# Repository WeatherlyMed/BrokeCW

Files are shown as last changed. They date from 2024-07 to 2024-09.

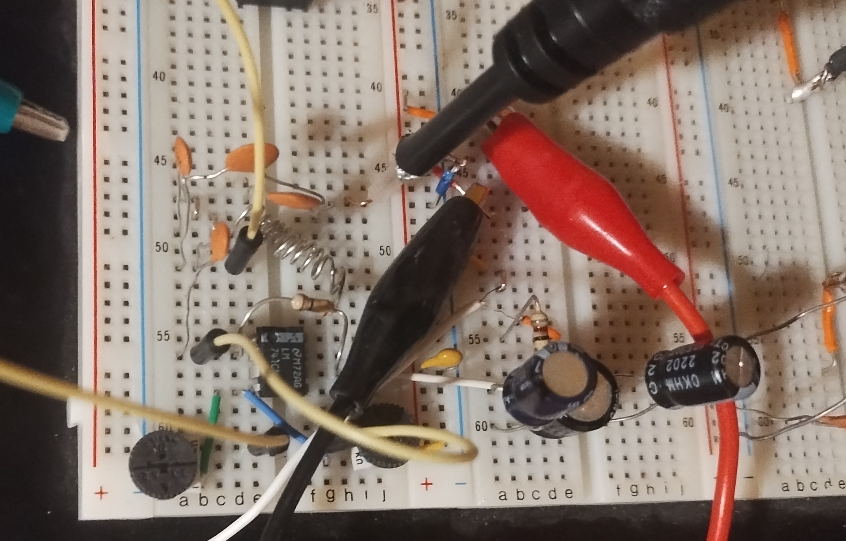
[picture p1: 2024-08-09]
receiver/testing/IMG_20240808_234810944~2.jpg

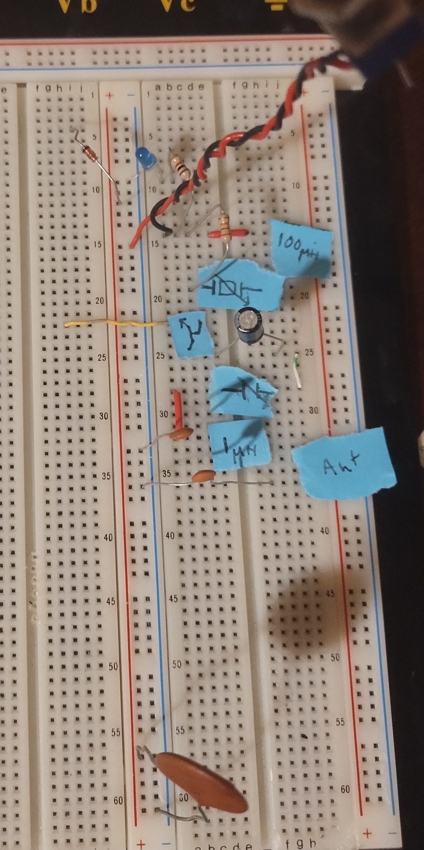
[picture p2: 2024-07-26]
artifact/withMyMaterials.jpg

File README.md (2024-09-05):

# BrokeCW
A 40m Ham Radio Transeiver build intended to be cheaper than an pixie radio while allowing for change in frequency and includes a autokey for iambic CW keyers
## Schematic for Best design with autokey: https://github.com/WeatherlyMed/BrokeCW/blob/main/artifact/ButtonSchematic.pdf


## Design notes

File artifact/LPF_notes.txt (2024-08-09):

low-pass filter (LPF) allows low-frequency signals to pass through while cuting out higher-frequency signals. 

How Low-Pass Filters Work
Basic Principle:

Pass Band: Frequencies below a certain cutoff frequency are allowed to pass through the filter.
Stop Band: Frequencies above the cutoff frequency are attenuated or blocked.
Components:

Resistor (R): Provides impedance to the circuit.
Capacitor (C): Blocks low-frequency signals but allows high-frequency signals to pass through.
Inductor (L): Blocks high-frequency signals while allowing low-frequency signals to pass.
Cutoff Frequency:

The cutoff frequency (f_c) is the point where the filter starts to attenuate the signal. It is defined by the following equations:
For RC filters: f_c = 1 / (2 * π * R * C)
For RL filters: f_c = R / (2 * π * L)
Types of Low-Pass Filters
RC Low-Pass Filter:

Components: Resistor and Capacitor.
Function: Attenuates high frequencies based on the RC time constant.
Equation: Cutoff frequency f_c = 1 / (2 * π * R * C)
Applications: Used in audio systems, signal conditioning.
RL Low-Pass Filter:

Components: Resistor and Inductor.
Function: Attenuates high frequencies based on the RL time constant.
Equation: Cutoff frequency f_c = R / (2 * π * L)
Applications: Used in power supplies and audio systems.
LC Low-Pass Filter:

Components: Inductor and Capacitor.
Function: Offers steeper attenuation than RC or RL filters due to its resonant properties.
Equation: Cutoff frequency f_c = 1 / (2 * π * sqrt(L * C))
Applications: Used in radio frequency circuits and signal processing.
Active Low-Pass Filter:

Components: Includes operational amplifiers along with resistors and capacitors.
Function: Provides gain and can be designed with various filter orders.
Applications: Used in more complex signal processing applications requiring high performance.

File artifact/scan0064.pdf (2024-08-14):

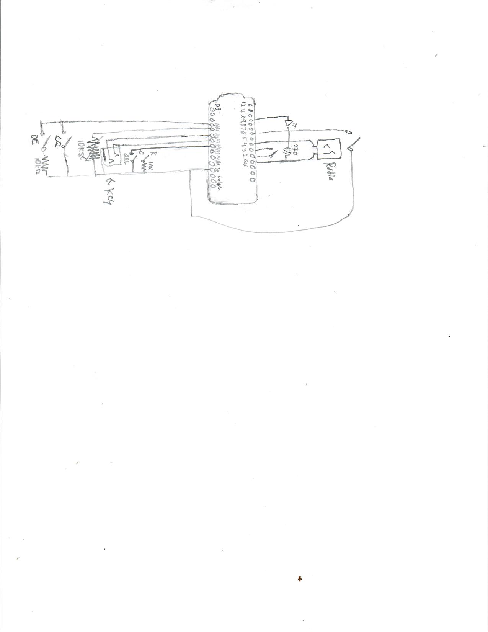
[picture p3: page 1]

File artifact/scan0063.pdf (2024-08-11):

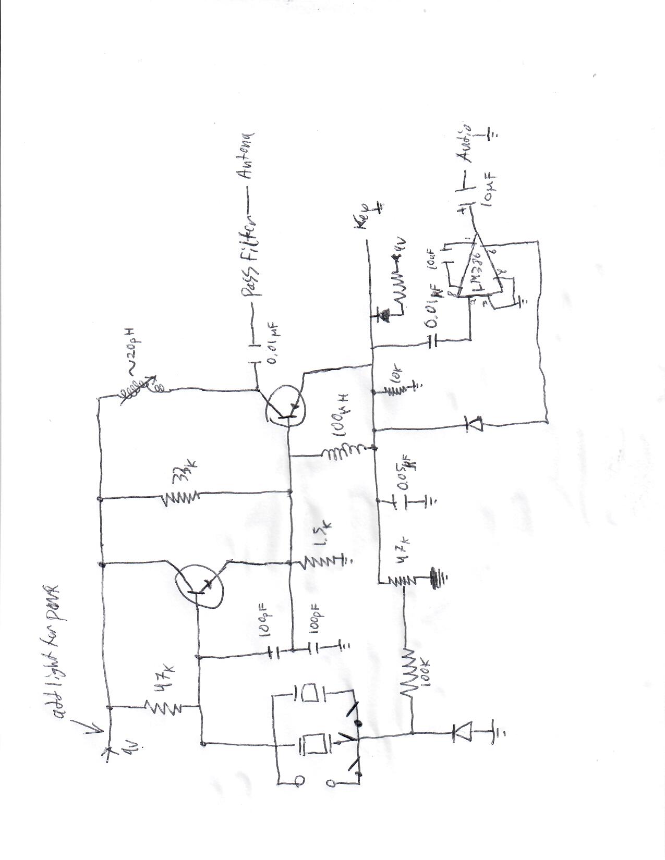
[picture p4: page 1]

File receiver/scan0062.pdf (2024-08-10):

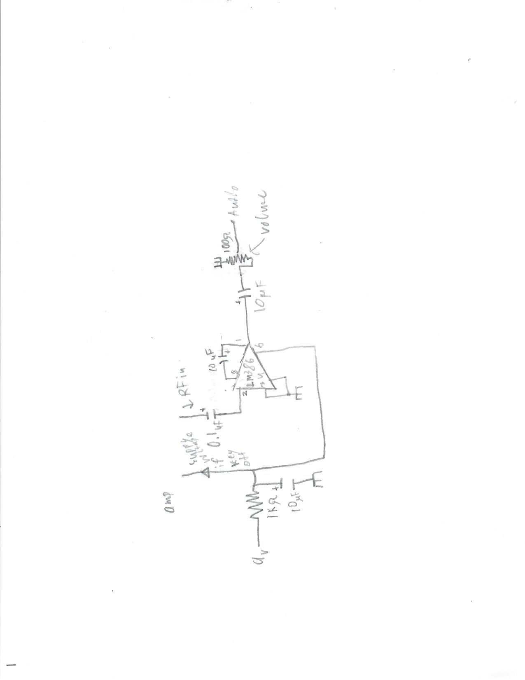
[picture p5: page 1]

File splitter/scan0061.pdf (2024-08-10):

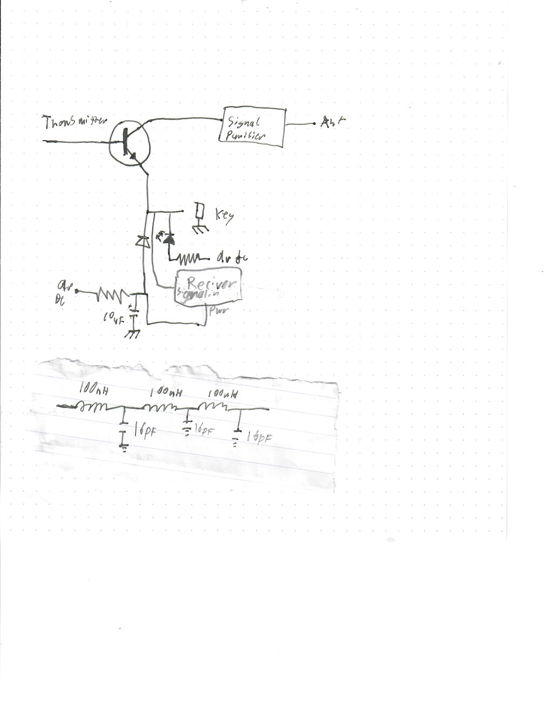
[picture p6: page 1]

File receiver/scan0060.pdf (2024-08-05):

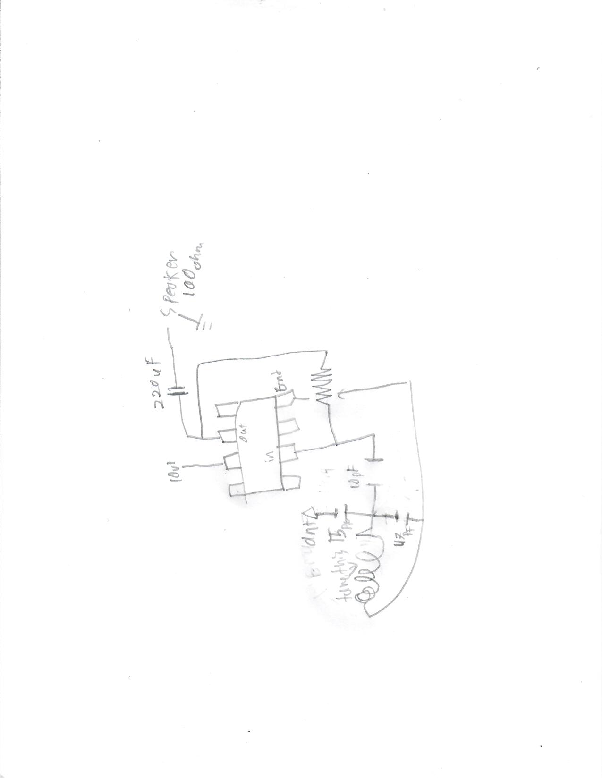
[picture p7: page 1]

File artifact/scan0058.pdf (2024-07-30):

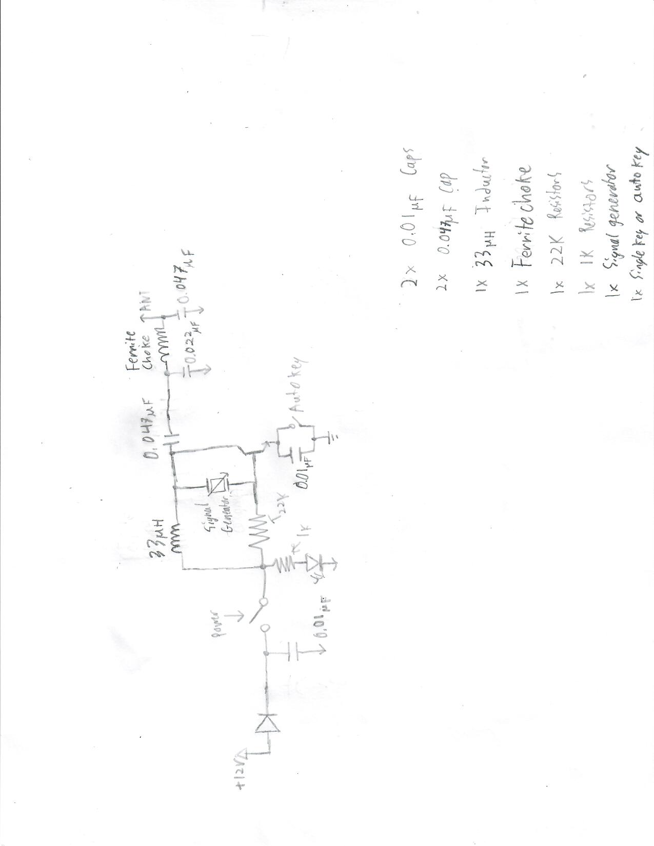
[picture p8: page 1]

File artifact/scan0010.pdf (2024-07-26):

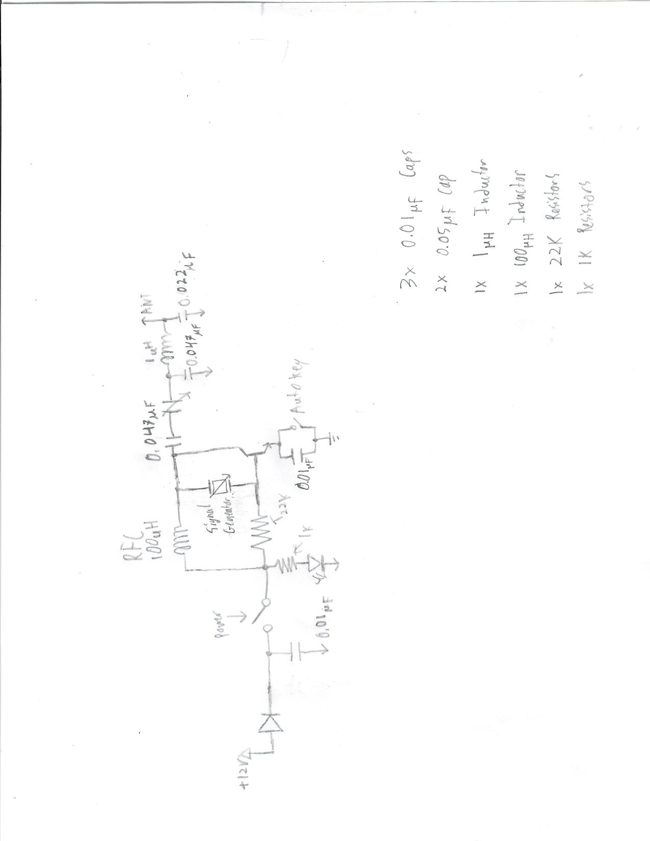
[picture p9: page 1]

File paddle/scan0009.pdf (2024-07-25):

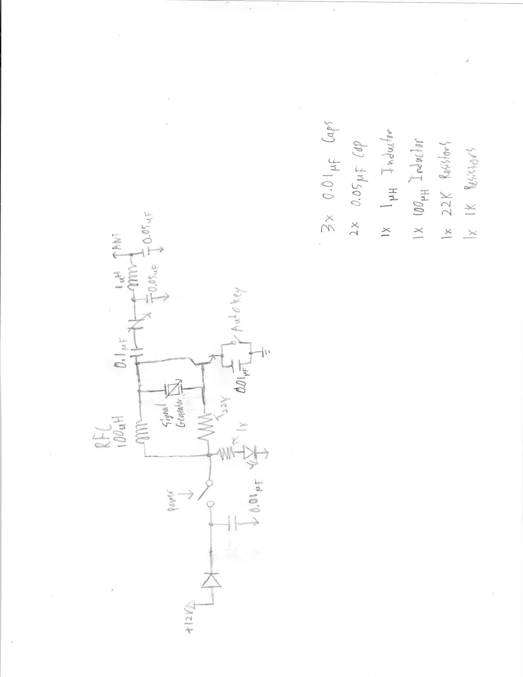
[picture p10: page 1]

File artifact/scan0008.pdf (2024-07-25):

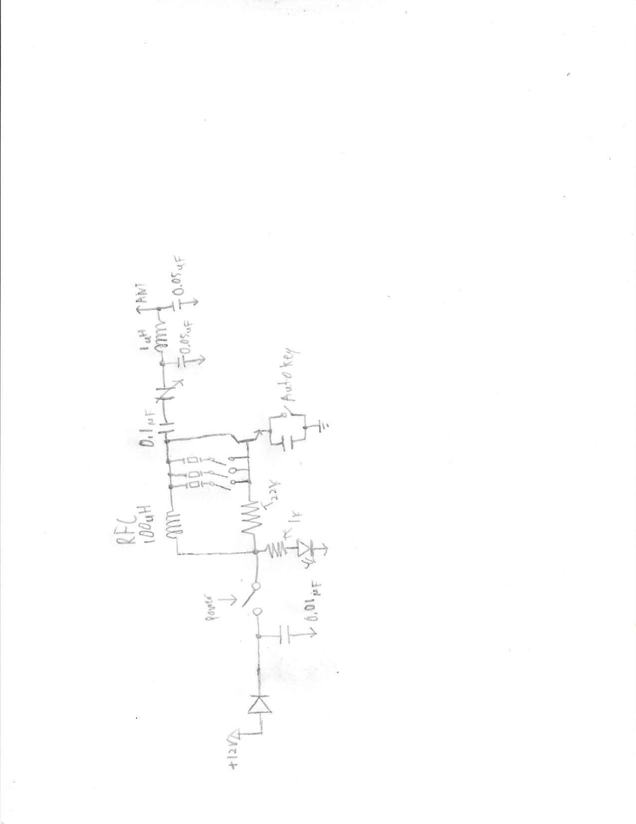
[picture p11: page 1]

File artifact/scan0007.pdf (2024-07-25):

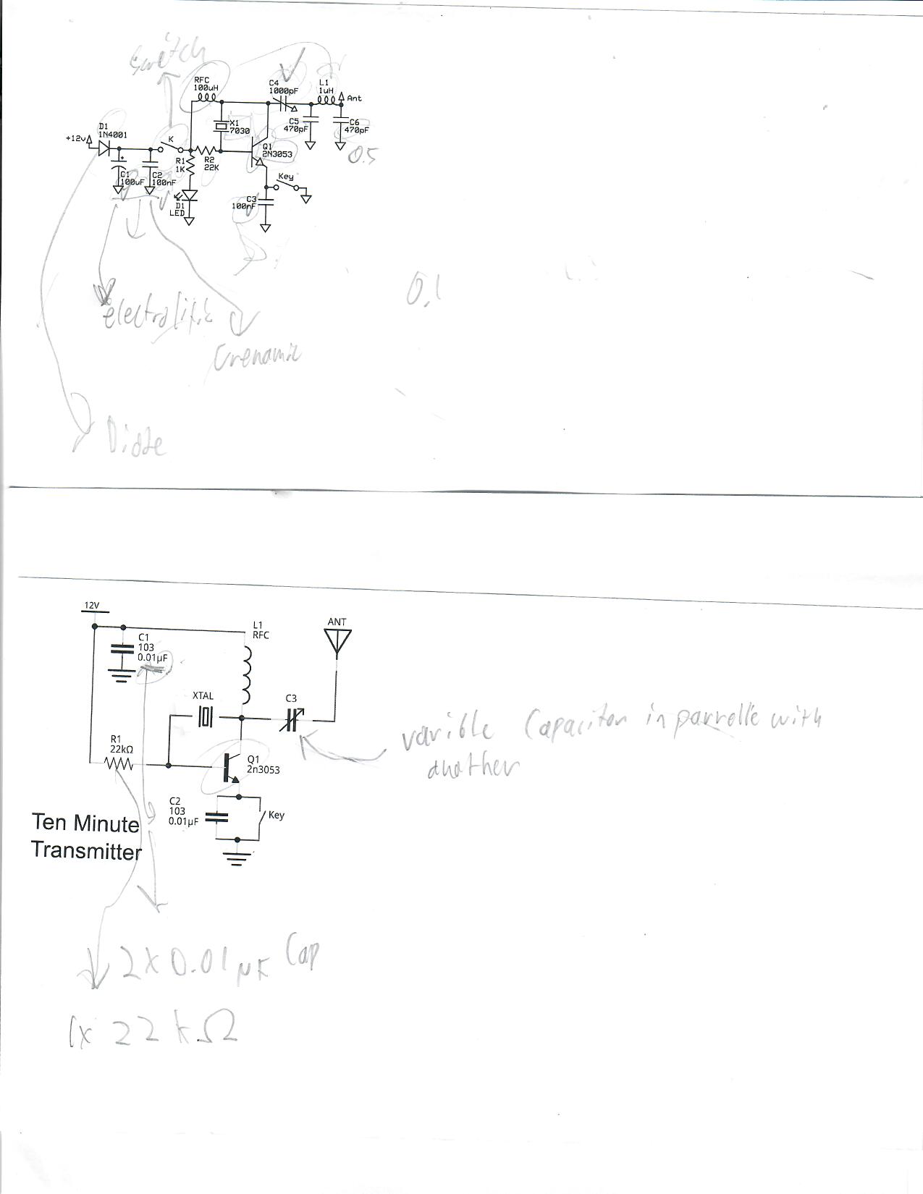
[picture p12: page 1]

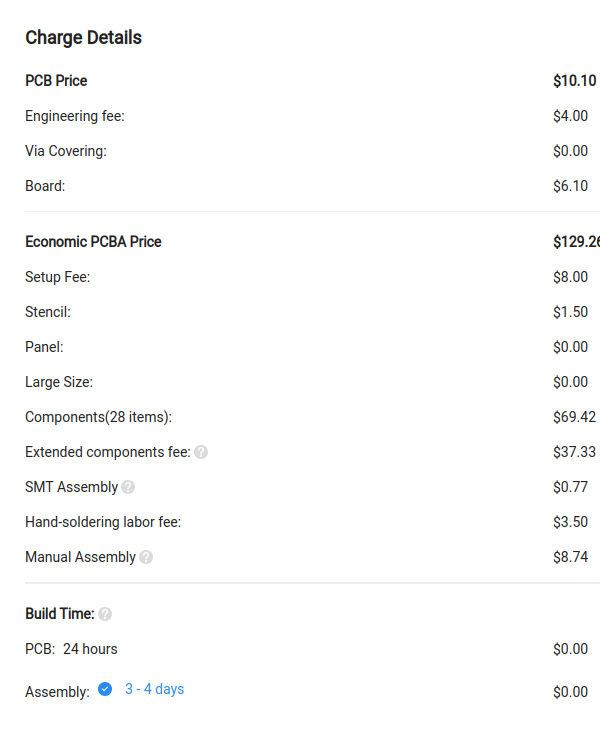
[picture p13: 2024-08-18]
artifact/Screenshot from 2024-08-17 22-34-50.png

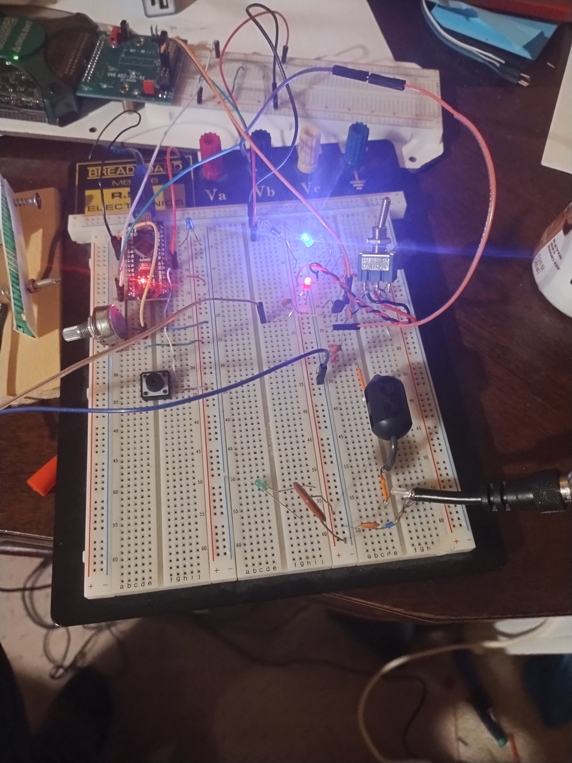
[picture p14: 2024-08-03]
artifact/IMG_20240802_214614031_HDR.jpg

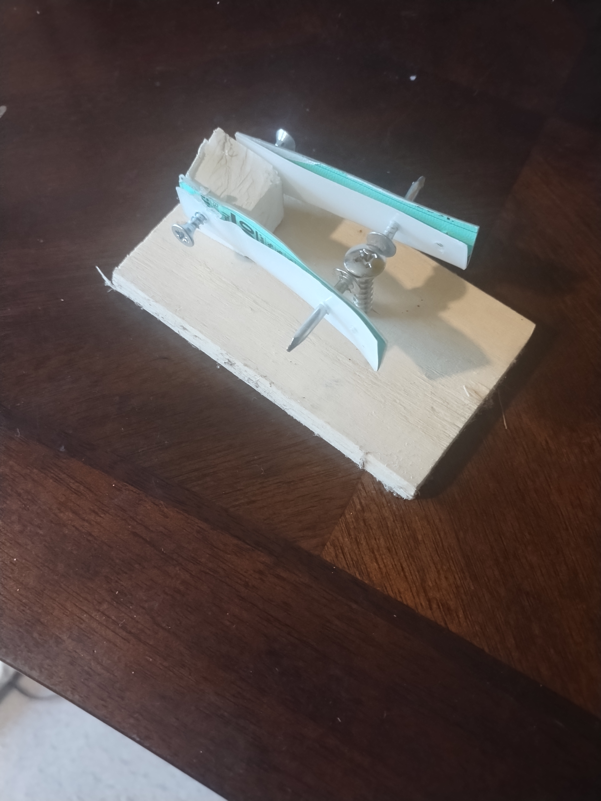
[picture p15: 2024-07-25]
paddle/Paddle.jpg

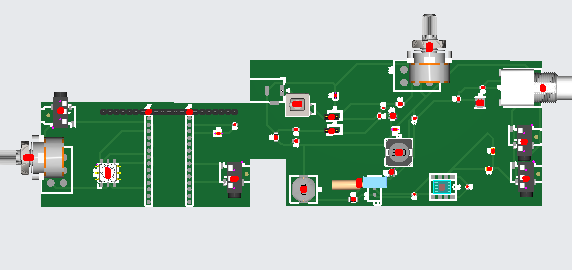
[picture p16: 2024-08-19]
artifact/Screenshot from 2024-08-18 22-14-38.png

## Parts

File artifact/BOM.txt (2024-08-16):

Resistors

2x R1: 47kΩ
CRGP2512F47K
R2: 33kΩ
AS0707J0333T5E
R3: 1kΩ
RTT121001FTP
R4: 470Ω
RTT25471JTE
R5: 10kΩ
RS-1210K1002FT
1x R6: 100kΩ 
PR02000201003JA100
R7: 10Ω
RMS10FT10R0
R8: 10kΩ
FCR1210KT10K0
R9: 220Ω
RM02FTN2200

Capacitors
C1: 0.1µF, 16V, Ceramic
CC0603KRX7R9BB104
C2: 100pF, Ceramic
CT81-6KV-07b-2b4-101K-2T3
C3: 16pF, Ceramic
C1005NP0160KGTS
C4: 10µF
CC1210ZKY5V9BB106
C3-4: 0.1uF
1H103ZC4P-3F-ZNR

Inductors
1x L1: 100µH
CY105-100uH
1x L2: 1uH
NRS4018T1R0NDGJ
1x L3: 22uH
SMDRH105R-220MT

Diodes
D2: 1N4001
C145491
D3: 1N4148
C402212

Transistors
1x Q1: 9013 (NPN Transistor) 
9013-H
Q2: 8050 (NPN Transistor)
8050-D
Crystals

Y1: 7.023MHz Crystal Oscillator(connector for it)
C22373846
Integrated Circuits

1x U1: LM386 (Low Voltage Audio Power Amplifier)

Connectors

1x J1: Power Input Connector
DC-005QB-2.0-SU-R
and
9V 100mm
1x J2: Coax Connector (for ANT)
DOSIN-801-0038
4x J3: 3.5mm Jack
C431535
3x J4: LED Indicator pink
FC-1608WPD-462M
2x J5: 15Pin Connector
B-2100S15P-A110

Miscellaneous

1x W1: 50kΩ Variable Resistor (Potentiometer)
RK16312A0BKH
1x W2 10k Variable Resistor
RK16312101A2
1x W3: 100 Varible Resistor
C330439
W4: pwr Switch
A22AB
5x W5: Option Buttons Keyer
KMS231GPLFS

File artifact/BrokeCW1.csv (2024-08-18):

Id | Designator | Footprint | Quantity | Designation | Supplier and ref
1 | J5,J6 | Hirose_DF13-03P-1.25DSA_1x03_P1.25mm_Vertical | 2 | Conn_01x03_Pin | C22373846
2 | C7 | C_Disc_D5.1mm_W3.2mm_P5.00mm | 1 | C0.01uF | C695370
3 | SW6,SW4,SW2,SW5,SW3 | SW_SPST_CK_KMS2xxGP | 5 | CK_KMS2xxGP | C318884
4 | R2 | R_1210_3225Metric | 1 | R33k | C4216
5 | C1,C2 | C_0805_2012Metric | 2 | C 10uF | C19702
6 | R4 | R_2512_6332Metric | 1 | R | C4410
7 | R1 | R_2512_6332Metric | 1 | R47k | C17713
8 | D3,D2 | LED_0402_1005Metric | 2 | LED | C2297
9 | RV2 | Potentiometer_Bourns_3296X_Horizontal | 1 | R_100ohm | C330439
10 | C4,C3 | C_Disc_D5.1mm_W3.2mm_P5.00mm | 2 | C | C1846
11 | C8,C9 | C_0402_1005Metric | 2 | C_Small | C107145
12 | RV3 | Potentiometer_Alps_RK163_Dual_Horizontal | 1 | R_Potentiometer_10k | C470593
13 | L1 | L_10.4x10.4_H4.8 | 1 | L_100uH | C5140330
14 | C6,C5 | C_Disc_D7.0mm_W2.5mm_P5.00mm | 2 | C100p | C1790
15 | R8 | Resistor_THT:R_Axial_DIN0414_L11.9mm_D4.5mm_P15.24mm_Horizontal | 1 | R_Small | 0603WAF2000T5E
16 | J4,J3 | Jack_3.5mm_KoreanHropartsElec_PJ-320D-4A_Horizontal | 2 | AudioJack3_Ground | C95562
17 | J10 | Jack_3.5mm_KoreanHropartsElec_PJ-320D-4A_Horizontal | 1 | AudioJack3_Radio | C95562
18 | L3 | L_10.4x10.4_H4.8 | 1 | L | C10165
19 | R7,R5,R3 | R_1210_3225Metric | 3 | R10K | C17902
20 | Q1 | TO-92_Inline | 1 | 9013 | C6749
21 | L2 | L_Taiyo-Yuden_MD-4040 | 1 | 1uH | C92958
22 | SW1 | SW_CK_JS202011CQN_DPDT_Straight | 1 | SW_DPDT_x2 | C712185
23 | J8 | PinHeader_1x15_P2.54mm_Vertical | 1 | Conn_01x15_PinRight | C124373
24 | J9 | Jack_3.5mm_KoreanHropartsElec_PJ-320D-4A_Horizontal | 1 | AudioJack3_Key | C95562
25 | D1 | D_DO-41_SOD81_P7.62mm_Horizontal | 1 | D_C145491 | C2128
26 | J2 | BNC_Amphenol_B6252HB-NPP3G-50_Horizontal | 1 | Conn_Coaxial | C709673
27 | J7 | PinHeader_1x15_P2.54mm_Vertical | 1 | Conn_01x15_PinLeft | C124373
28 | R6 | R_Axial_DIN0414_L11.9mm_D4.5mm_P15.24mm_Horizontal | 1 | R100k | C17900
29 | J1 | BarrelJack_Wuerth_6941xx301002 | 1 | Barrel_Jack_MountingPin | C7428648
30 | U1 | DIP-8_W7.62mm_SMDSocket_SmallPads | 1 | LM386 | C5157706
31 | RV1 | Potentiometer_Alps_RK163_Dual_Horizontal | 1 | R_Pot50k | C470593
32 | Q2 | TO-92_Inline | 1 | 8050 | C2150

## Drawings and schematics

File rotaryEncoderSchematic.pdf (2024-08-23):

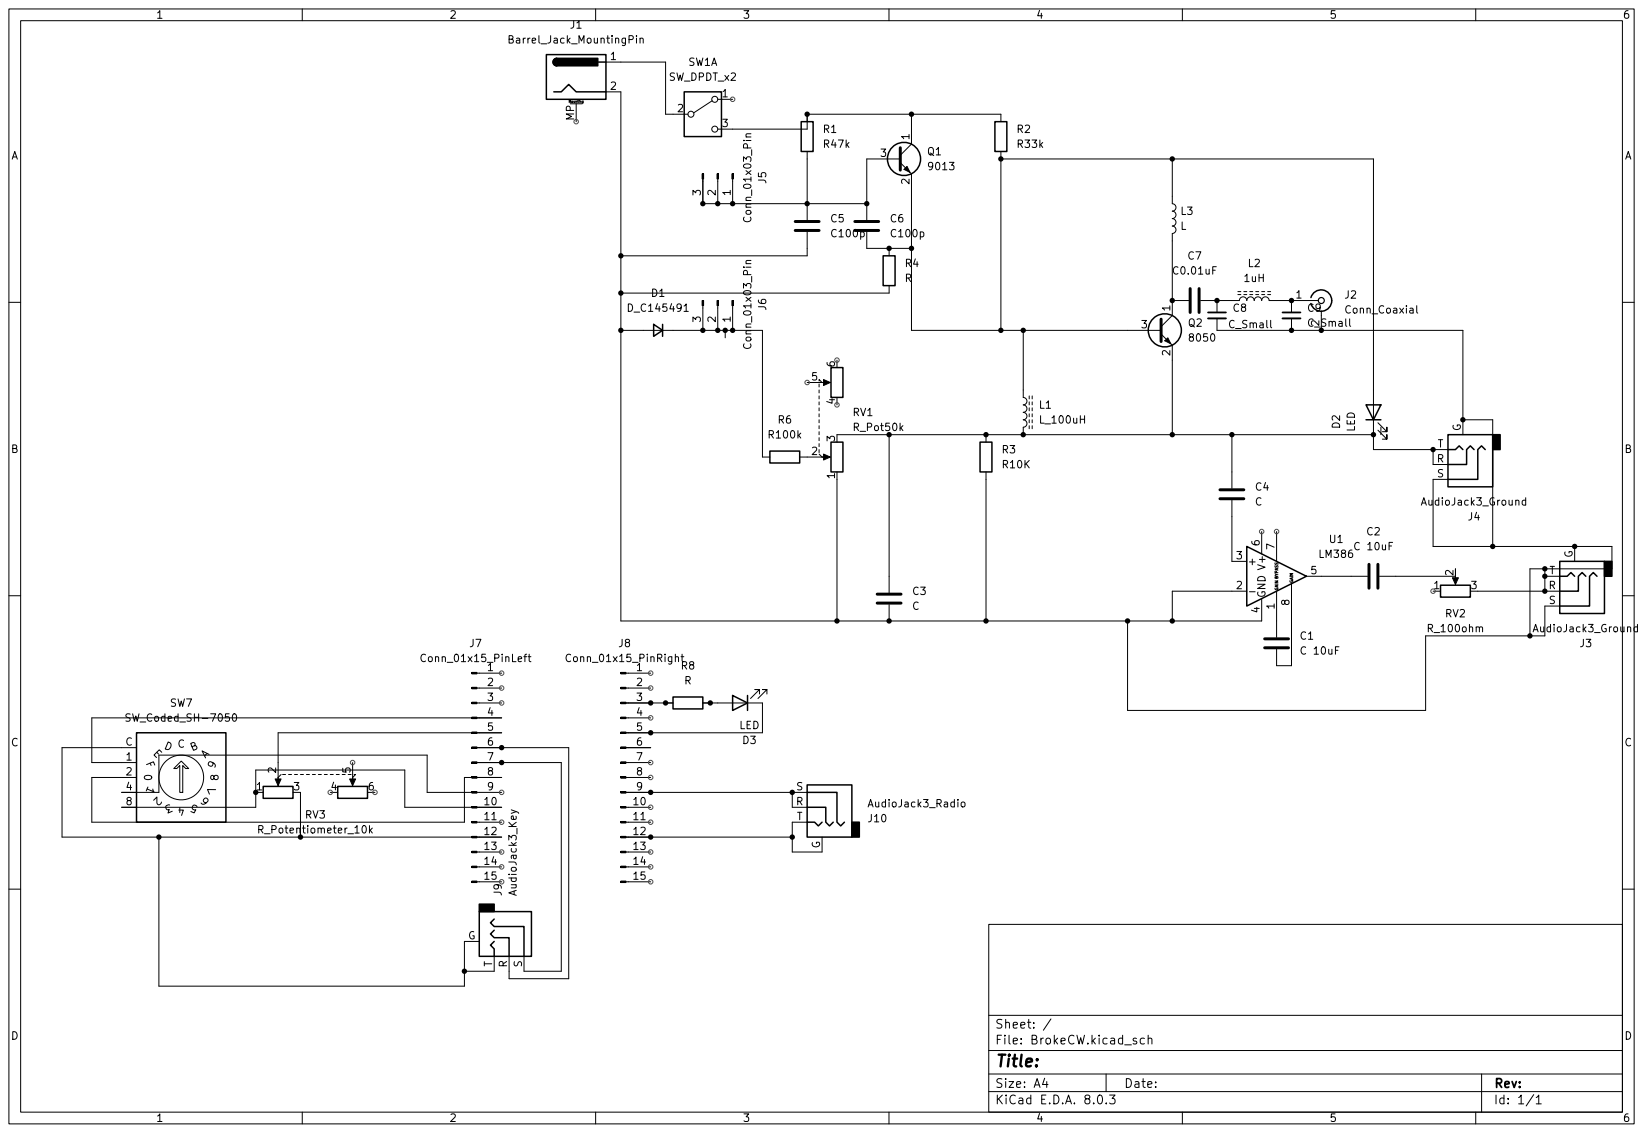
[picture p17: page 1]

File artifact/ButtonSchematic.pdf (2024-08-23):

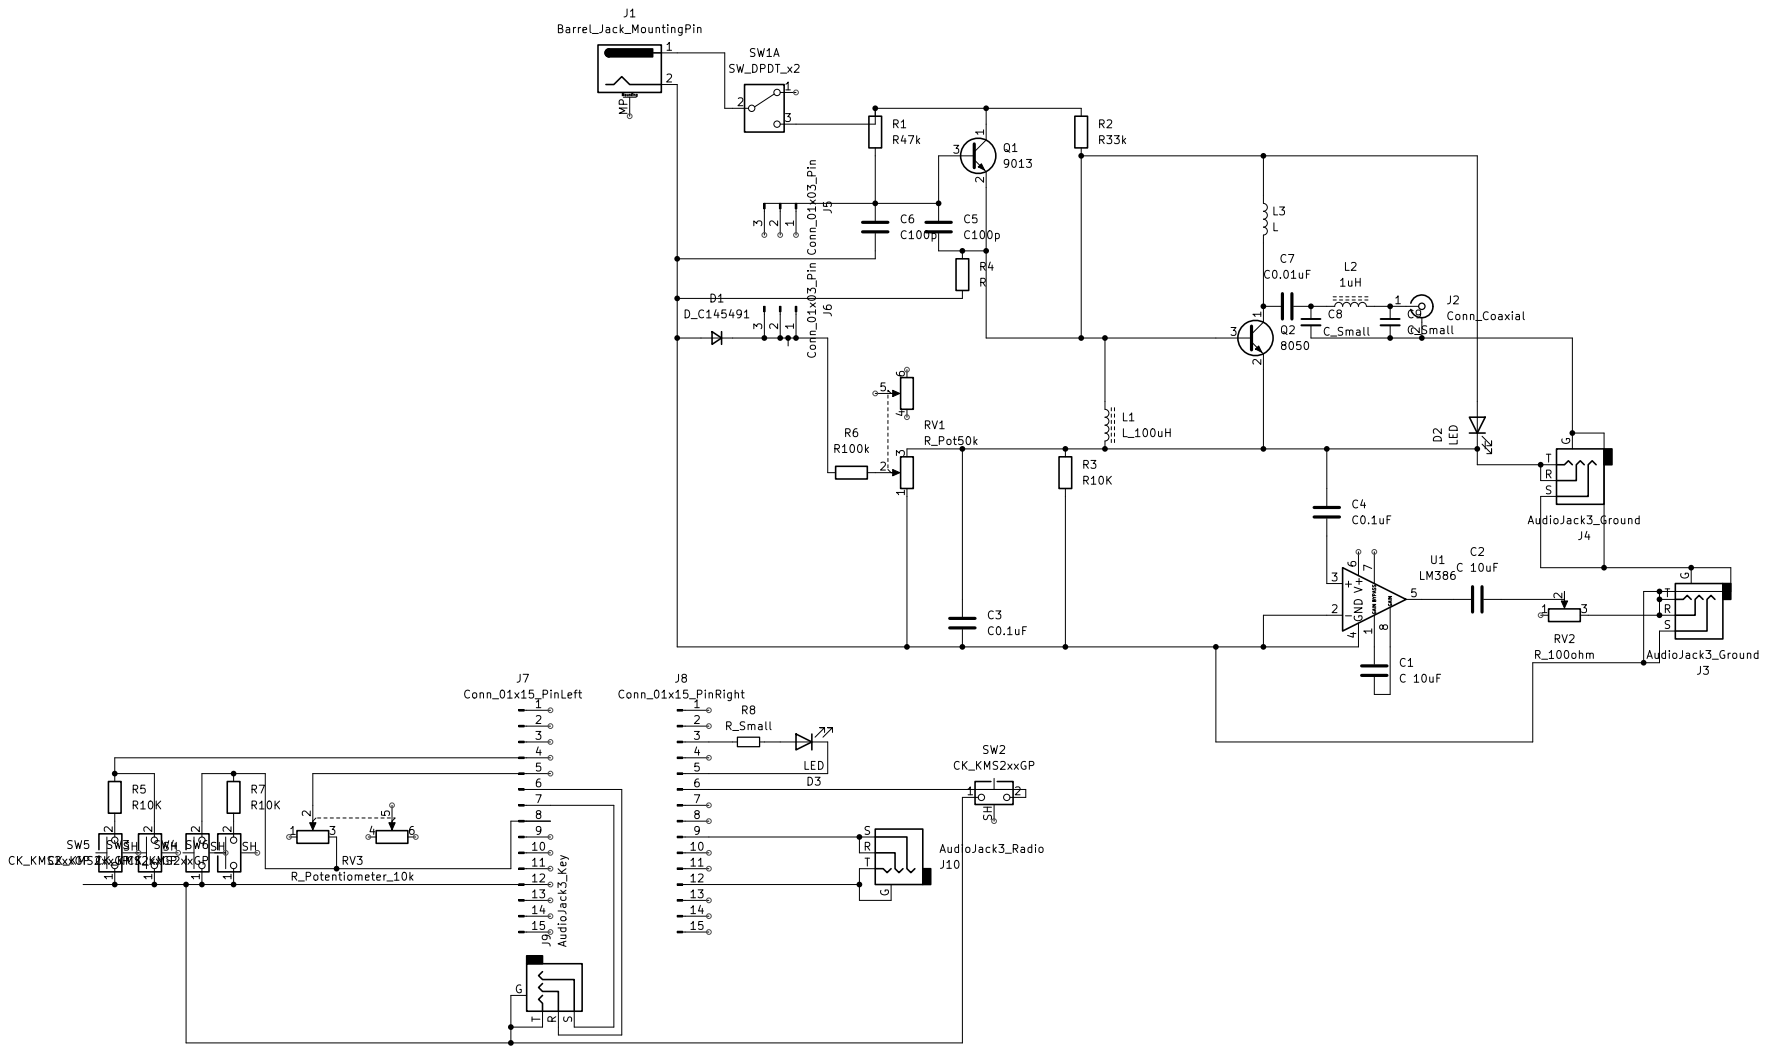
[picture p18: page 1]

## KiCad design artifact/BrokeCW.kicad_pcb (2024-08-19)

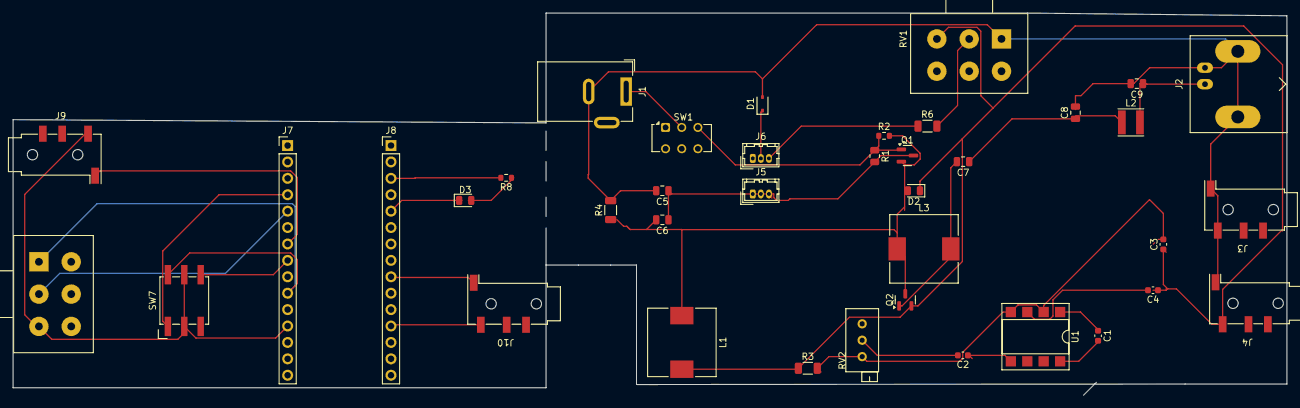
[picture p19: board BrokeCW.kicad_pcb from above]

Board: 2 copper layers, 197.2 x 59.2 mm, 39 parts (0 on the bottom side), 27 nets.

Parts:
C1, C2: C 10uF; C_0603_1608Metric
C3, C4: C; C_0603_1608Metric
C5, C6: C100p; C_0805_2012Metric
C7: C0.01uF; C_0805_2012Metric
C8, C9: C_Small; C_0805_2012Metric
D1: D_C145491; D_SOD-323
D2, D3: LED; LED_0805_2012Metric
J1: Barrel_Jack_MountingPin; BarrelJack_Wuerth_6941xx301002
J2: Conn_Coaxial; BNC_Amphenol_B6252HB-NPP3G-50_Horizontal
J3, J4: AudioJack3_Ground; Jack_3.5mm_KoreanHropartsElec_PJ-320D-4A_Horizontal
J5, J6: Conn_01x03_Pin; Hirose_DF13-03P-1.25DSA_1x03_P1.25mm_Vertical
J7: Conn_01x15_PinLeft; PinHeader_1x15_P2.54mm_Vertical
J8: Conn_01x15_PinRight; PinHeader_1x15_P2.54mm_Vertical
J9: AudioJack3_Key; Jack_3.5mm_KoreanHropartsElec_PJ-320D-4A_Horizontal
J10: AudioJack3_Radio; Jack_3.5mm_KoreanHropartsElec_PJ-320D-4A_Horizontal
L1: L_100uH; L_10.4x10.4_H4.8
L2: 1uH; L_Taiyo-Yuden_MD-4040
L3: L; L_10.4x10.4_H4.8
Q1: 9013; SOT-23
Q2: 8050; SOT-23
R1: R47k; R_0805_2012Metric
R2: R33k; R_0603_1608Metric
R3: R10K; R_1206_3216Metric
R4: R; R_1206_3216Metric
R6: R100k; R_1206_3216Metric
R8: R; R_0603_1608Metric
RV1: R_Pot50k; Potentiometer_Alps_RK163_Dual_Horizontal
RV2: R_100ohm; Potentiometer_Bourns_3296X_Horizontal
RV3: R_Potentiometer_10k; Potentiometer_Alps_RK163_Dual_Horizontal
SW1: SW_DPDT_x2; SW_CK_JS202011CQN_DPDT_Straight
SW7: SW_Coded_SH-7050; Nidec_Copal_SH-7010B
U1: LM386; DIP-8_W7.62mm_SMDSocket_SmallPads

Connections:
unnamed: C1.1, U1.1 (GAIN)
unnamed: C1.2, U1.8 (GAIN)
unnamed: C2.1, U1.5
unnamed: C2.2, RV2.2
unnamed: C7.1, C8.1, L2.1
unnamed: C3.2, C5.2, C8.2, C9.2, D1.2 (A), J1.2, J2.2 (Ext), J3.S, J3.T, J4.S, R3.2, R4.2, RV1.1, RV2.3, U1.2 (-), U1.4 (GND)
unnamed: D1.1 (K), J6.1, J6.2, J6.3, R6.1
unnamed: C6.2, D2.2 (A), L1.1, L3.1, Q1.2 (E), Q2.3 (B), R2.2, R4.1
unnamed: C3.1, C4.1, D2.1 (K), J4.T, L1.2, Q2.2 (E), R3.1, RV1.3
unnamed: D3.2 (A), R8.1
unnamed: D3.1 (K), J8.5
unnamed: C9.1, J2.1 (In), L2.2
unnamed: C5.1, C6.1, J5.1, J5.2, J5.3, Q1.3 (B), R1.2
unnamed: J7.4, SW7.1
unnamed: J7.5, RV3.2
unnamed: J7.7, J9.S
unnamed: J7.8, SW7.2
unnamed: J7.10, RV3.1, SW7.8
unnamed: J7.12, J9.T, RV3.3, SW7.C
unnamed: J8.3, R8.2
unnamed: J8.9, J10.S
unnamed: J8.12, J10.T
unnamed: Q1.1 (C), R1.1, R2.1, SW1.3 (C)
unnamed: C7.2, L3.2, Q2.1 (C)
unnamed: R6.2, RV1.2
unnamed: J1.1, SW1.2 (B)
unnamed: C4.2, U1.3 (+)

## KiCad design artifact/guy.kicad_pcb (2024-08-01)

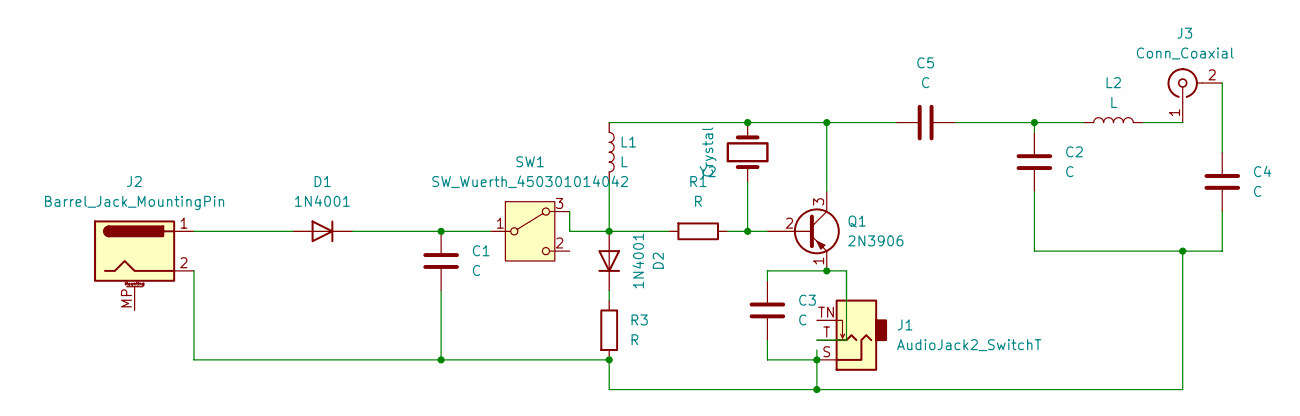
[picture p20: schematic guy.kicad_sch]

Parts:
C1, C2, C3, C4, C5: C; C_Rect_L4.0mm_W2.5mm_P2.50mm
D1, D2: 1N4001; D_DO-41_SOD81_P10.16mm_Horizontal
J1: AudioJack2_SwitchT; Jack_3.5mm_Lumberg_1503_07_Horizontal
J2: Barrel_Jack_MountingPin; BarrelJack_CLIFF_FC681465S_SMT_Horizontal
J3: Conn_Coaxial; BNC_Amphenol_B6252HB-NPP3G-50_Horizontal
L1, L2: L; L_Bourns-SRN6028
Q1: 2N3906; TO-92_Inline
R1, R3: R; R_Axial_DIN0207_L6.3mm_D2.5mm_P5.08mm_Vertical
SW1: SW_Wuerth_450301014042; SW_Slide-03_Wuerth-WS-SLTV_10x2.5x6.4_P2.54mm
Y2: Crystal; Crystal_HC49-U_Vertical

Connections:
unnamed: C1.2, C2.2, C3.2, C4.2, J1.S, J2.2, R3.2
unnamed: C2.1, C5.2, L2.1
unnamed: D1.2 (A), J2.1
unnamed: C1.1, D1.1 (K), SW1.1 (B)
unnamed: D2.2 (A), L1.2, R1.2, SW1.3 (A)
unnamed: D2.1 (K), R3.1
unnamed: C4.1, J3.2 (Ext)
unnamed: J3.1 (In), L2.2
unnamed: Q1.2 (B), R1.1, Y2.1
unnamed: C5.1, L1.1, Q1.3 (C), Y2.2
unnamed: C3.1, J1.T, Q1.1 (E)

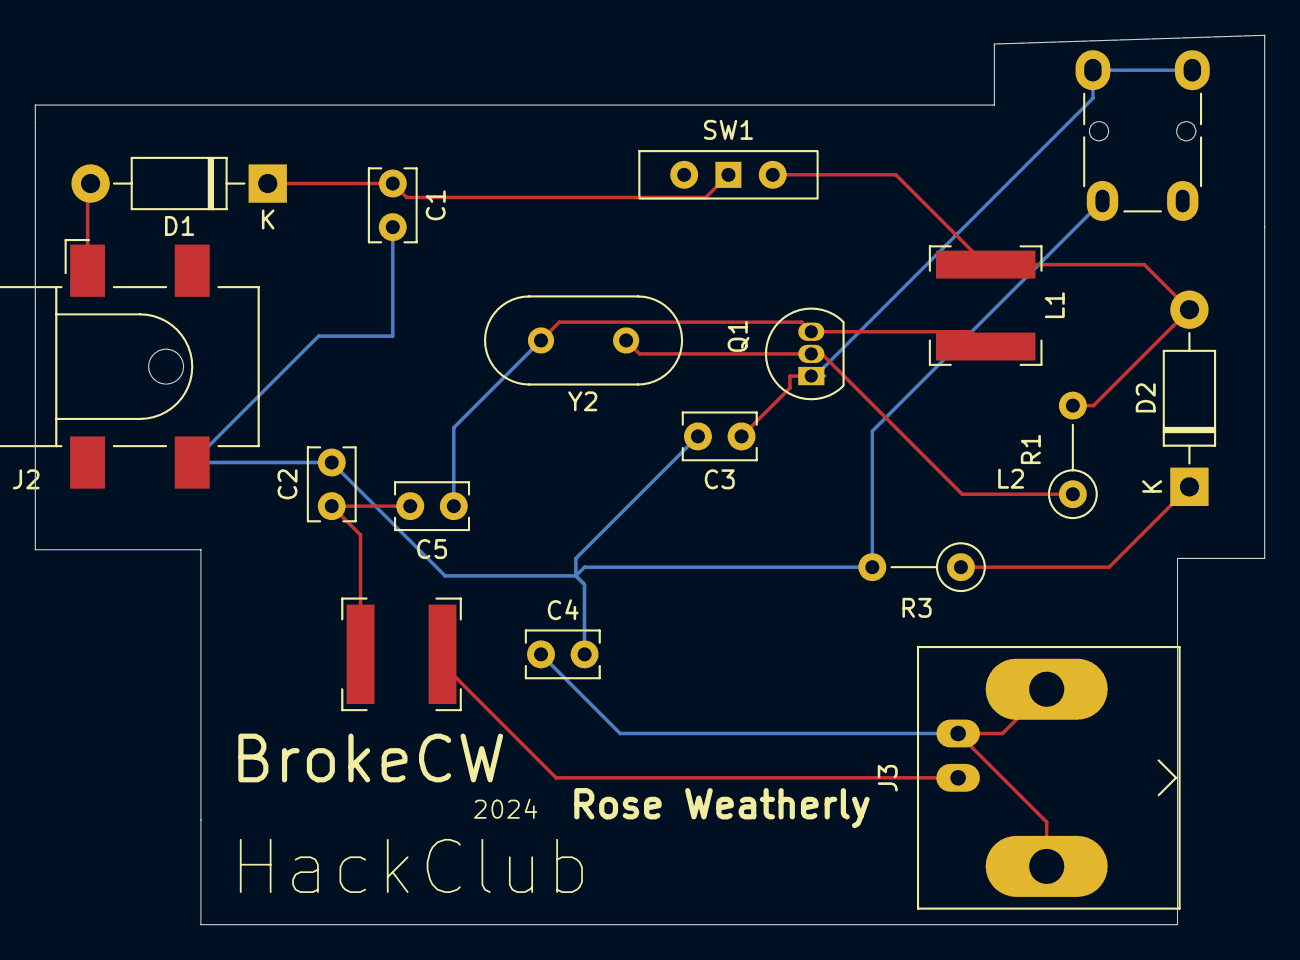
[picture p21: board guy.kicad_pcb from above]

Board: 2 copper layers, 70.5 x 51.0 mm, 17 parts (0 on the bottom side), 11 nets.

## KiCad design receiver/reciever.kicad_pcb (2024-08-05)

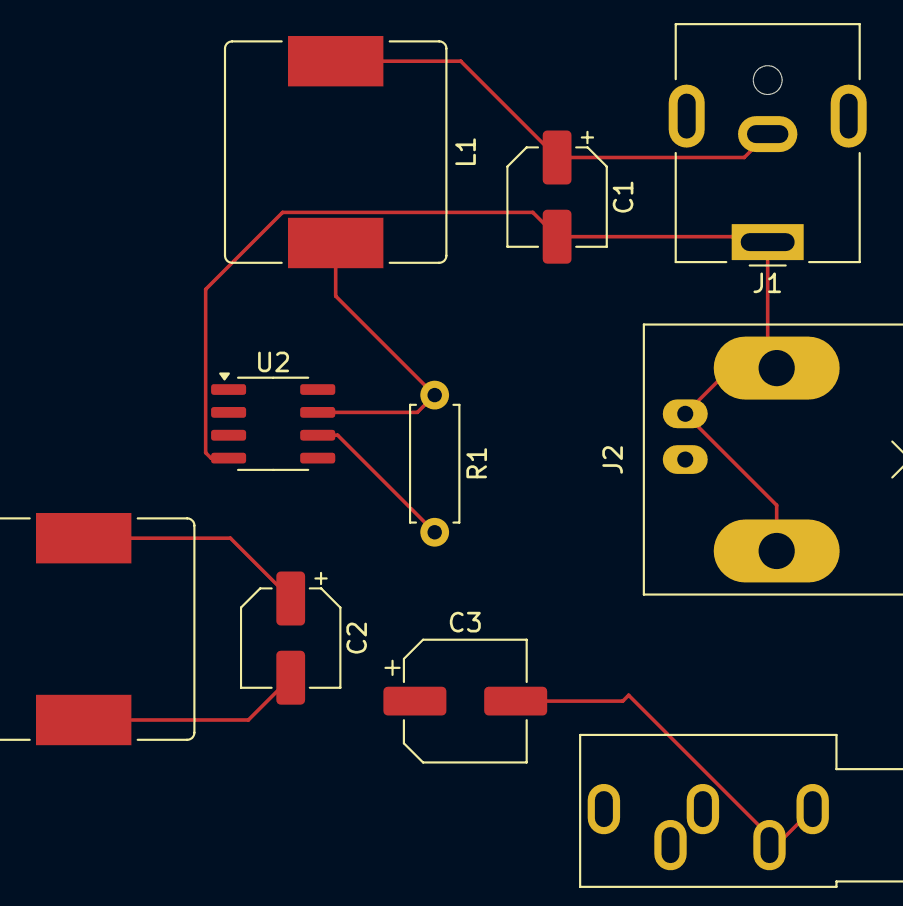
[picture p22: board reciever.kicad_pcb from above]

Board: 2 copper layers, 10 parts (0 on the bottom side), 7 nets.

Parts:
C1, C2: C_Polarized_Small; CP_Elec_5x5.4
C3: C_Polarized_Small; CP_Elec_6.3x5.4
J1: Barrel_Jack_Switch; BarrelJack_CUI_PJ-063AH_Horizontal
J2: Conn_Coaxial_Power; BNC_Amphenol_B6252HB-NPP3G-50_Horizontal
J3: AudioJack2_Ground_Switch; Jack_3.5mm_CUI_SJ1-3535NG_Horizontal
L1, L2: L_Ferrite; L_Bourns_SRR1210A
R1: R_Small; R_Axial_DIN0207_L6.3mm_D2.5mm_P7.62mm_Horizontal
U2: LM741; SOIC-8_3.9x4.9mm_P1.27mm

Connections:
unnamed: C1.1, J1.2, L1.1
unnamed: C3.1, R1.2, U2.6
unnamed: C3.2, J3.S, J3.T
unnamed: C1.2, J1.1, J2.2 (Ext), U2.4 (V-)
unnamed: C2.1, J2.1 (In), L2.2
unnamed: C2.2, L2.1, U2.2 (-)
unnamed: L1.2, R1.1, U2.7 (V+)

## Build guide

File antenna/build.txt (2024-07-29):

Measure out 33 feet of speaker wire cut and split it into 2 33' peices (this is for 7.1Mhz)
get a bnc connector - Or if you are me cut open a BNC wire and isloate gnd and pwr
soldier each end of the bnc to an indivdual wire
wrap the joints in electrical tape
use a peice of plasic to prevent stress on the solider 
drill holes and use zip ties to attach

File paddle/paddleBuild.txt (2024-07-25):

Materials:
- 2x Flexy Bits (plastic from arizona gallon bottle)
- 2x 1/4" Coductive Pieces (Roofing Nails)
- Center Ground Rod (Random screw)
- Wire to connect everything (speaker wire)
- Insulative building materials (PVC and wood trim)

Place the center ground rod and a upright peice of building material on a flat peice of material

Attach the flex bits to the upright and add conductive peices at the other end
Wire it up and attach to a keyer

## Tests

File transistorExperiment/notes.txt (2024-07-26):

All avalible transistors use higher voltage than avalible from arduino keyer and this means even a mosfet is not feasible.
However, reversing the code for the keyer so that low is hit on up tones and high on down tones should help with this.
This also means the ground must be universal so that arduino ground(low) is also the 12v Low signal.

Notes:
All designs analysised used a single key to signal using a iambic (double) paddle means ajustments will need to me made.

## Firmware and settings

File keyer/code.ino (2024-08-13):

const int LED = 9;
const int dit = A2;
const int dah = A3;
const int key = 4;
const int cqDePin = A0; // Combined pin for CQ and DE
const int qrlKPin = A4; // Combined pin for QRL and K
const int setCallSignButton = 6;
const int reset = 3;
const int speed = A1;
const int threshold = 512;

int DPM = 25 * 50;
float element = 3.0;
float ditLang, dahLang;
int ditStat = 0;
int dahStat = 0;

String morseCode = "";  
String userCallSign = ""; 
String otherCallSign = ""; 
unsigned long lastInputTime = 0;
const unsigned long pauseTime = 1000; 

String morseLetters[] = {".-", "-...", "-.-.", "-..", ".", "..-.", "--.", "....", "..", ".---",
                         "-.-", ".-..", "--", "-.", "---", ".--.", "--.-", ".-.", "...", "-",
                         "..-", "...-", ".--", "-..-", "-.--", "--..", "-----", ".----", "..---",
                         "...--", "....-", ".....", "-....", "--...", "---..", "----."};

char letters[] = {'A', 'B', 'C', 'D', 'E', 'F', 'G', 'H', 'I', 'J',
                  'K', 'L', 'M', 'N', 'O', 'P', 'Q', 'R', 'S', 'T',
                  'U', 'V', 'W', 'X', 'Y', 'Z', '0', '1', '2', '3',
                  '4', '5', '6', '7', '8', '9'};

void setup(){
  pinMode(dit, INPUT);
  pinMode(dah, INPUT);
  pinMode(LED, OUTPUT);
  pinMode(key, OUTPUT);
  pinMode(setCallSignButton, INPUT);
  Serial.begin(9600); 
  digitalWrite(LED, LOW);
  ditLang = 100;
  dahLang = ditLang * element;
}

void keyUp(){
  digitalWrite(key, HIGH);
  digitalWrite(LED, LOW);
}

void keyDown(){
  digitalWrite(key, LOW);
  digitalWrite(LED, HIGH);
}

void doDit(){
  keyDown();
  delay(ditLang);
  keyUp();
  morseCode += "."; 
  ditStat = 0;
  lastInputTime = millis(); 
}

void doDah(){
  keyDown();
  delay(dahLang);
  keyUp();
  morseCode += "-"; 
  dahStat = 0;
  lastInputTime = millis(); 
}

void decodeMorse(){
  for (int i = 0; i < sizeof(morseLetters)/sizeof(morseLetters[0]); i++) {
    if (morseCode == morseLetters[i]) {
      Serial.print(letters[i]);
      break;
    }
  }
  morseCode = ""; 
}

void sendCQ(){
  String cqSequence = "-.-.--.-.--.-."; 
  for (int i = 0; i < cqSequence.length(); i++) {
    if (cqSequence[i] == '.') {
      doDit();
    } else if (cqSequence[i] == '-') {
      doDah();
    }
    delay(ditLang); 
  }
  delay(dahLang * 2); 
}

void sendCallSign(String callSign){
  for (int i = 0; i < callSign.length(); i++) {
    char c = callSign[i];
    if (c == ' ') {
      delay(dahLang * 2); 
    } else {
      String morse = getMorseCode(c);
      for (int j = 0; j < morse.length(); j++) {
        if (morse[j] == '.') {
          doDit();
        } else if (morse[j] == '-') {
          doDah();
        }
        delay(ditLang); 
      }
      delay(dahLang); 
    }
  }
  delay(dahLang * 2); 
}

String getMorseCode(char c){
  c = toupper(c);
  for (int i = 0; i < sizeof(letters)/sizeof(letters[0]); i++) {
    if (c == letters[i]) {
      return morseLetters[i];
    }
  }
  return ""; 
}

void sendQRL(){
  String qrlSequence = "--.-.-...-.."; 
  for (int i = 0; i < qrlSequence.length(); i++) {
    if (qrlSequence[i] == '.') {
      doDit();
    } else if (qrlSequence[i] == '-') {
      doDah();
    }
    delay(ditLang); 
  }
  delay(dahLang * 2); 
}

void sendDE(){
  String deSequence = "-...."; 
  for (int i = 0; i < deSequence.length(); i++) {
    if (deSequence[i] == '.') {
      doDit();
    } else if (deSequence[i] == '-') {
      doDah();
    }
    delay(ditLang); 
  }
  delay(dahLang * 2); 
}

void sendK(){
  String kSequence = "-.-"; 
  for (int i = 0; i < kSequence.length(); i++) {
    if (kSequence[i] == '.') {
      doDit();
    } else if (kSequence[i] == '-') {
      doDah();
    }
    delay(ditLang); 
  }
  delay(dahLang * 2); 
}

void typeOtherCallSign() {
  Serial.println("Enter the call sign of the person you're talking to: ");
  while (Serial.available() == 0) {} // Wait for input
  otherCallSign = Serial.readStringUntil('\n'); // Read input
  otherCallSign.trim(); // Remove any trailing whitespace
  Serial.print("Other Call Sign: ");
  Serial.println(otherCallSign);
}

void loop(){
  ditStat = analogRead(dit);
  dahStat = analogRead(dah);
  if (ditStat >= 900){
    doDit();
    delay(ditLang);
  }
  else if (dahStat >= 900){
    doDah();
    delay(ditLang);
  }

  int cqDeValue = analogRead(cqDePin); 
  if (cqDeValue < 500 && cqDeValue > 100) { 
    sendCQ();
  } else if (cqDeValue >= 500) { 
    sendDE();
  }

  int qrlKValue = analogRead(qrlKPin); 
  if (qrlKValue < 500 && qrlKValue > 100) { 
    sendQRL();
  } else if (qrlKValue >= 500) { 
    sendK();
  }

  if (digitalRead(setCallSignButton) == HIGH && userCallSign.length() > 0){
    sendCallSign(userCallSign);
  }

  if (Serial.available() > 0) {
    typeOtherCallSign();
  }
  
  if (millis() - lastInputTime > pauseTime && morseCode != "") {
    decodeMorse();
  }
}

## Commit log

2024-07-25 Radio Out Circuit Notes
2024-07-26 Update to circuit with my current materials
2024-07-26 Ignore BOM will fix in morning
2024-07-26 current assembly
2024-08-01 organise directory
    [gu23.5.kicad_pcb, guy21.5.kicad_sch, guy22.5.kicad_sch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]
2024-08-09 Create antenna test
2024-08-09 Update antenna test
2024-08-23 reorganised the files
    [BrokeCW.csv, BrokeCW.kicad_pcb, BrokeCW.kicad_sch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]
